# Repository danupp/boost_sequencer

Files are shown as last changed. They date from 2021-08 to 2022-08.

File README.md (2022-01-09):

# boost_sequencer
Universal sequencer for radio applications with 12 to 28V boost regulator for coaxial relays. More info at: sm6vfz.wordpress.com

---
Changelog/notes:

-Ta bort lödpasta från TPs.\
-Schottky: SS16_R1_00001\
-PMOS: SI2347DS-T1-GE3\
-NMOS: SI2318DS-T1-BE3\
-2k2->3k0

Löd alltid relä vid test.

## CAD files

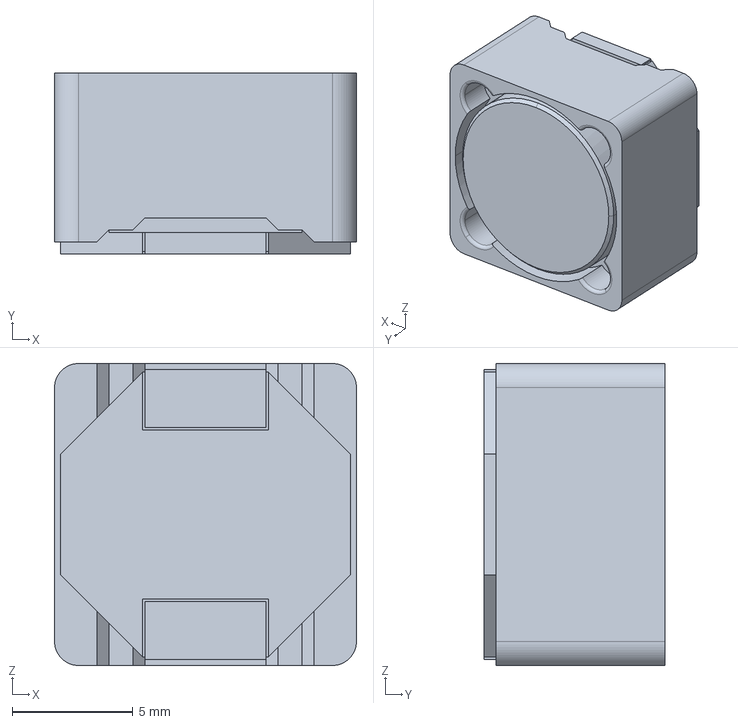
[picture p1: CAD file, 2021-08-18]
kicad/pm127sh-330m-rc.stp
12.5 x 7.50 x 12.5 mm

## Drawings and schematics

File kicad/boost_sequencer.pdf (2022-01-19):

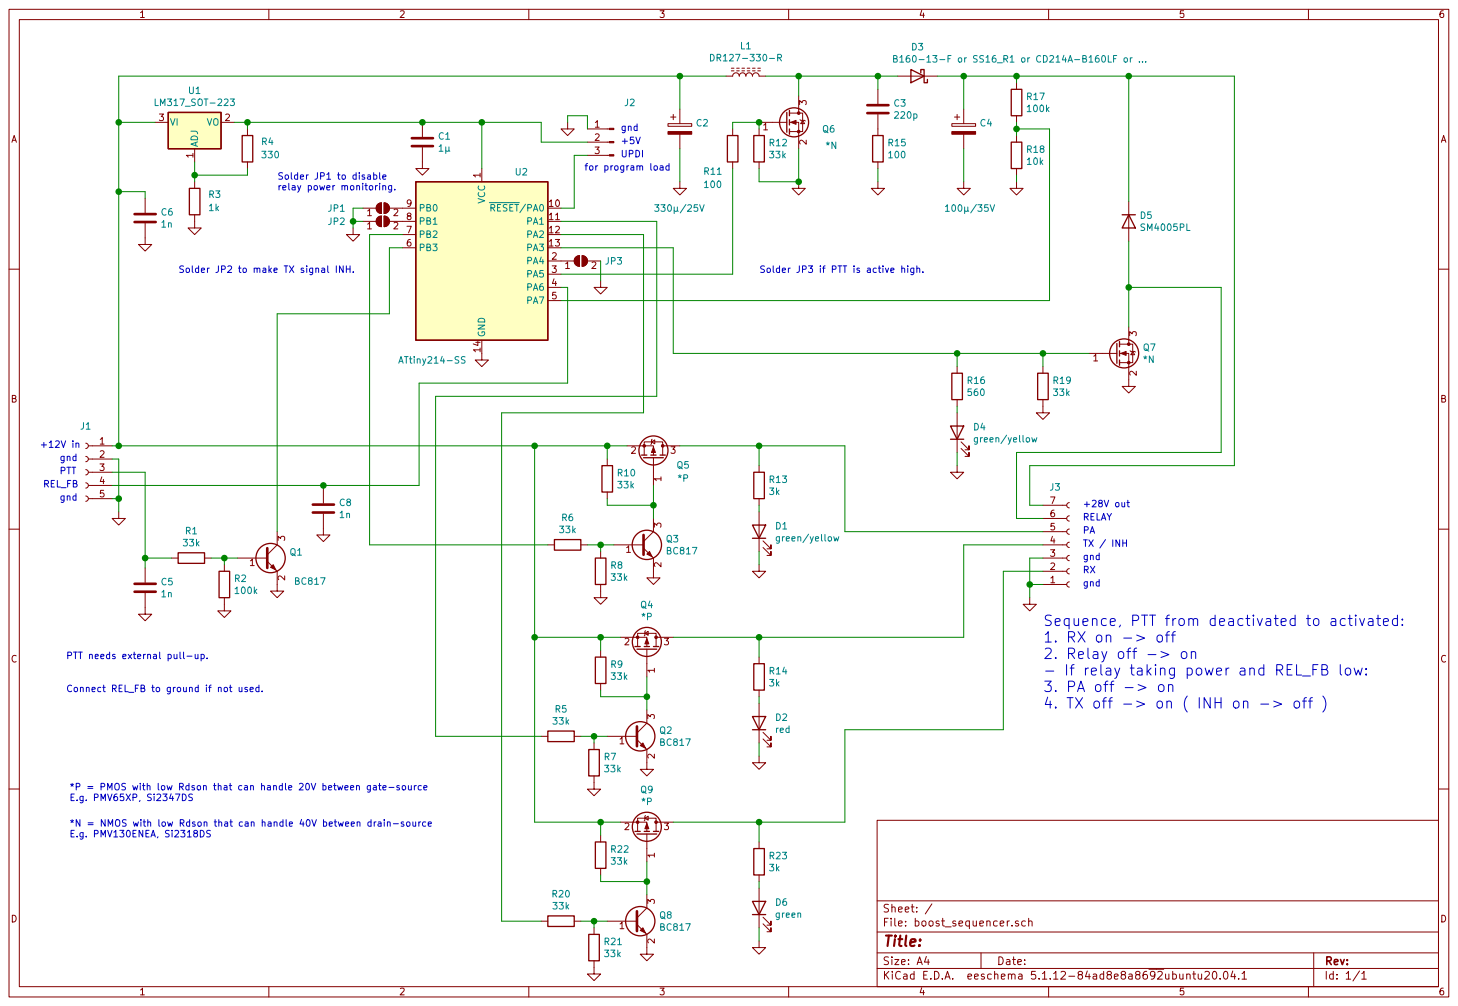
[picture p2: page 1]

1 RESET/PA0 10 PA1 11 PA2 12 PA3 13 GND 14 PA4 2 PA5 3 PA6 4 PA7 5 PB3 6 PB2 7 PB1 8 PB0 9 U2 ATtiny214-SS ADJ 1 VO 2 VI 3 U1

Solder JP2 to make TX signal INH.

Solder JP3 if PTT is active high.

+28V out +12V inPTTConnect REL_FB to ground if not used.

1. RX on -> off
2. Relay off -> on
- If relay taking power and REL_FB low:
3. PA off -> on

*P = PMOS with low Rdson that can handle 20V between gate-source
E.g. PMV65XP, Si2347DS

*N = NMOS with low Rdson that can handle 40V between drain-source E.g. PMV130ENEA, Si2318DS

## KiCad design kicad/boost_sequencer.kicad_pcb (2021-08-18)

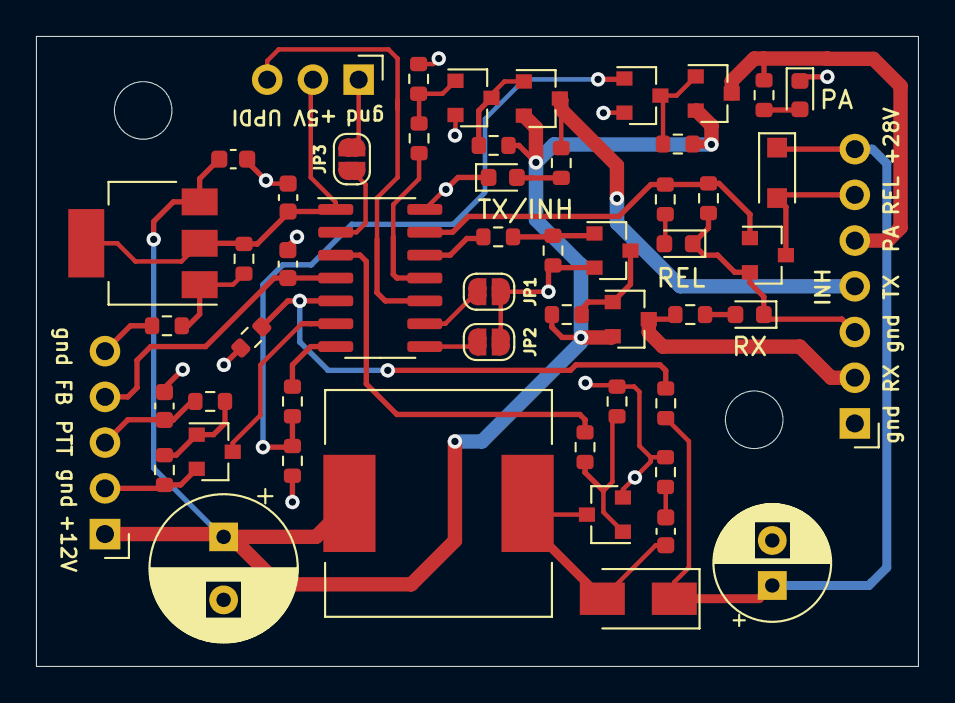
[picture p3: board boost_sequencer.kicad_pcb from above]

Board: 2 copper layers, 49.0 x 35.0 mm, 54 parts (0 on the bottom side), 36 nets.

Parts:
C1: 1µ; C_0603_1608Metric
C2: 330µ/25V; CP_Radial_D8.0mm_P3.50mm
C3: 220p; C_0603_1608Metric
C4: 100µ/35V; CP_Radial_D6.3mm_P2.50mm
C5, C6, C8: 1n; C_0603_1608Metric
D1, D2: red; LED_0603_1608Metric
D3: B160-13-F; D_SMA
D4: yellow; LED_0603_1608Metric
D5: SM4005PL; D_SOD-123F
D6: green; LED_0603_1608Metric
J1: Conn_01x05_Female; PinHeader_1x05_P2.54mm_Vertical
J2: Conn_01x03_Male; PinHeader_1x03_P2.54mm_Vertical
J3: Conn_01x07_Female; PinHeader_1x07_P2.54mm_Vertical
JP1, JP2, JP3: SolderJumper_2_Open; SolderJumper-2_P1.3mm_Open_RoundedPad1.0x1.5mm
L1: DR127-330-R; L_12x12mm_H8mm
Q1, Q2, Q3, Q8: BC817; SOT-23
Q4, Q5, Q9: PMV65XPE; SOT-23
Q6, Q7: PMV130ENEA; SOT-23
R1, R5, R6, R7, R8, R9, R10, R12, R19, R20, R21, R22: 33k; R_0603_1608Metric
R2, R17: 100k; R_0603_1608Metric
R3: 1k; R_0603_1608Metric
R4: 330; R_0603_1608Metric
R11, R15: 100; R_0603_1608Metric
R13, R14, R23: 2k2; R_0603_1608Metric
R16: 560; R_0603_1608Metric
R18: 10k; R_0603_1608Metric
U1: LM317_SOT-223; SOT-223-3_TabPin2
U2: ATtiny214-SS; SOIC-14_3.9x8.7mm_P1.27mm

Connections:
GND: C1.2, C2.2, C4.2, C5.2, C6.2, C8.2, D1.1, D2.1, D4.1, D6.1, J1.2, J1.5, J2.1, J3.1, J3.3, JP1.1, JP2.1, JP3.2, Q1.2, Q2.2, Q3.2, Q6.2, Q7.2, Q8.2, R2.2, R3.1, R7.2, R8.2, R12.2, R15.2, R18.2, R19.2, R21.2, U2.14
unnamed: C1.1, J2.2, R4.2, U1.2, U2.1
unnamed: C2.1, C6.1, J1.1, L1.1, Q4.2, Q5.2, Q9.2, R9.1, R10.1, R22.1, U1.3
unnamed: C3.1, D3.2, L1.2, Q6.3
unnamed: C3.2, R15.1
unnamed: C4.1, D3.1, D5.1, J3.7, R17.1
unnamed: C5.1, J1.3, R1.2
unnamed: C8.1, J1.4, U2.4
unnamed: D1.2, R13.2
unnamed: D2.2, R14.2
unnamed: D4.2, R16.2
unnamed: D5.2, J3.6, Q7.3
unnamed: D6.2, R23.2
unnamed: J2.3, U2.10
unnamed: J3.2, Q9.3, R23.1
unnamed: J3.4, Q4.3, R14.1
unnamed: J3.5, Q5.3, R13.1
unnamed: JP1.2, U2.9
unnamed: JP2.2, U2.8
unnamed: JP3.1, U2.2
unnamed: Q1.1, R1.1, R2.1
unnamed: Q1.3, U2.6
unnamed: Q2.1, R5.1, R7.1
unnamed: Q2.3, Q4.1, R9.2
unnamed: Q3.1, R6.1, R8.1
unnamed: Q3.3, Q5.1, R10.2
unnamed: Q6.1, R11.2, R12.1
unnamed: Q7.1, R16.1, R19.1, U2.13
unnamed: Q8.1, R20.1, R21.1
unnamed: Q8.3, Q9.1, R22.2
unnamed: R3.2, R4.1, U1.1
unnamed: R5.2, U2.11
unnamed: R6.2, U2.7
unnamed: R11.1, U2.3
unnamed: R17.2, R18.1, U2.5
unnamed: R20.2, U2.12

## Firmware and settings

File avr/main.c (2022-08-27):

// Targets an ATtiny214

#define F_CPU 3333333
#include <avr/io.h>
#include <avr/interrupt.h>
#include <util/delay.h>

#define PTT PIN3_bm // PB3
#define PA PIN2_bm // PB2
#define TX_INH PIN1_bm // PA1
#define RX PIN2_bm // PA2
#define RELAY PIN3_bm // PA3
#define BUCK_GATE PIN5_bm // PA5
#define BUCK_FB PIN7_bm // PA7 
#define REL_FB PIN6_bm // PA6
#define JP1 PIN0_bm // PB0
#define JP2 PIN1_bm // PB1
#define JP3 PIN4_bm // PA4

#define PTT_ACTIVE ( ((PORTB.IN & PTT) && (jp3_soldered == 0)) || (!(PORTB.IN & PTT) && jp3_soldered) )

volatile uint8_t overload_flag;
volatile uint16_t cyclecount;

ISR(RTC_PIT_vect) { // 8 Hz - check overload

  RTC.PITINTFLAGS = 0x01; // clear flag
  if (overload_flag) {
    if (AC0.STATUS & AC_STATE_bm) // to make sure that we are not stuck above the set point voltage
      TCA0.SINGLE.CTRLA = 0b00000000; // DISABLE switching.
  }
  else {
    overload_flag = 0x01;
    AC0.INTCTRL = 0x01; // enable interrupt
  }
}

ISR(AC0_AC_vect) {
  AC0.STATUS = 0x01; // clear flag
  AC0.INTCTRL = 0x00; // disable interrupt
  overload_flag = 0x00;
}

ISR(PORTA_PORT_vect) {
  PORTA.INTFLAGS = 0x20; // clear flag
  cyclecount++;
}

void main () {

  uint8_t jp1_soldered, jp2_soldered, jp3_soldered;
  
  PORTA.DIR = TX_INH | RX | RELAY | BUCK_GATE; // outputs
  PORTA.PIN7CTRL = 0x04; // digital input disable for AINP0/PA7
  PORTA.OUT = 0x00;
  PORTB.DIR = PA;
  PORTB.PIN0CTRL = 0x08; // enable pull-up for JP1 - solder to disable relay power monitoring
  PORTB.PIN1CTRL = 0x08; // enable pull-up for JP2 - solder to make TX signal INH
  PORTA.PIN4CTRL = 0x08; // enable pull-up for JP3 - solder if PTT active high (n.b. BJT inverter)
  PORTB.PIN3CTRL = 0x08; // enable pull-up for PTT
  PORTA.PIN6CTRL = 0x08; // enable pull-up for REL_FB
  PORTB.OUT = 0x00;

  PORTMUX.CTRLA = 0x01; // Enable EVOUT0
  
  _delay_ms(200);

  if (PORTB.IN & JP1)
    jp1_soldered = 0;
  else
    jp1_soldered = 1;

  if (PORTB.IN & JP2)
    jp2_soldered = 0;
  else
    jp2_soldered = 1;

  if (PORTA.IN & JP3)
    jp3_soldered = 0;
  else
    jp3_soldered = 1;

  TCA0.SINGLE.PER = 67; // 20us period -> 50 kHz
  TCA0.SINGLE.CTRLA = 0b00000001; // DIV1 -> 0.3us/tick, ENABLE
    
  TCB0.CTRLB = 0x16; // Single shot, output enable
  TCB0.EVCTRL = 0x01; // Enable input capture, start counter at pos edge
  TCB0.CCMP = 30; // 10us for 12V in and 3.6A current in 33uH
  TCB0.CTRLA = 0x01; // ENABLE

  AC0.MUXCTRLA = 0b10000011; // Inverted output, DAC to neg in
  VREF.CTRLA = 0x03; // 4.3V
  DAC0.DATA = 151; // 151/255*4.3*(100+10)/10 = 28V
  
  DAC0.CTRLA = 0x01; // ENABLE

  AC0.CTRLA = 0b00100001; // Interrupt at neg edge, ENABLE
  
  EVSYS.SYNCCH0 = 0x02; // TCA0_OVF
  EVSYS.ASYNCCH0 = 0x01; // CCL_LUT0
  //EVSYS.ASYNCUSER8 = 0x01; // SYNCCH0 -> EVOUT0/PA2 to see max switch freq 
  EVSYS.ASYNCUSER2 = 0x01; // SYNCCH0 -> LUT0
  EVSYS.ASYNCUSER0 = 0x03; // ASYNCCH0 -> TCB0
  
  CCL.LUT0CTRLB = 0x63; // AC0 + EVENT0
  CCL.TRUTH0 = 0b10001000; // AND
  CCL.LUT0CTRLA = 0x01; // ENABLE
  CCL.CTRLA = 0x01; // ENABLE

  _delay_ms(100); // wait 100ms after start before enabling overload detection
  
  overload_flag = 0x00;
  
  while(RTC.STATUS);
  RTC.CLKSEL = 0x00; // Use 32 kHz from OSC32K
  while(RTC.PITSTATUS);
  RTC.PITINTCTRL = 0x01; // enable interrupt
  while(RTC.PITSTATUS);
  RTC.PITCTRLA = 0b01011001; // Enable, interrupt after 4096 cycles => 8Hz

  PORTA.OUT |= RX;
  if (jp2_soldered)
    PORTA.OUT |= TX_INH;
  
  sei();
  
  while(1) {
    if (PTT_ACTIVE) {
	_delay_us(10); // filter noise spikes
	if (PTT_ACTIVE) {
	    // go from Receive to Transmit
	    PORTA.OUT &= ~RX;
	    //_delay_ms(10);
	    PORTA.OUT |= RELAY;
	    _delay_ms(25);
	    cyclecount = 0;
	    PORTA.PIN5CTRL = 0x02; // Interrupt at rising edge on gate drive pin
	    _delay_ms(10); // measured to 15ms with the interrupts
	    PORTA.PIN5CTRL = 0x00; // disable interrupt
	    if ( ( ((cyclecount > (uint16_t)38) && (cyclecount < (uint16_t)600)) || jp1_soldered) && !(PORTA.IN & REL_FB)) {
	  // Continue if 4-80 % load on relay or JP1 soldered, and REL_FB low
	      _delay_ms(10);
	      PORTB.OUT |= PA;
	      _delay_ms(10);
	      if (jp2_soldered)
		PORTA.OUT &= ~TX_INH;
	      else
		PORTA.OUT |= TX_INH;
	    }
	    while (PTT_ACTIVE) {
		_delay_ms(1);
	      }
    
	    // from Transmit to Receive
	    if (jp2_soldered)
	      PORTA.OUT |= TX_INH;
	    else
	      PORTA.OUT &= ~TX_INH;
	    _delay_ms(10);
	    PORTB.OUT &= ~PA;
	    _delay_ms(10);
	    PORTA.OUT &= ~RELAY;
	    //_delay_ms(20);  -- Blind time if PTT activates again
	    for(uint8_t a=0; a<200; a++) {
	      _delay_us(100);
	      if(PTT_ACTIVE)
		break;
	    }
	    if(!PTT_ACTIVE)
	      PORTA.OUT |= RX;
    
	  }
      }
  }
}

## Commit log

2021-08-18 First complete commit
    [boost_sequencer.kicad_pcb, boost_sequencer.sch, pm127sh-330m-rc.stp]
2021-11-18 Fixed details in code. Added Gerber files.
    [boost_sequencer-B_Cu.gbr, boost_sequencer-B_Mask.gbr, boost_sequencer-Edge_Cuts.gbr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]
2022-01-14 Relay activates instantly. And updated schematic.
2022-01-19 New schematic pdf.
